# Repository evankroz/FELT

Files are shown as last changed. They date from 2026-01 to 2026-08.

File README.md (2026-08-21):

# FELT - Flight Environment Logging and Telemetry
A *light*weight (light as felt) Arduino system for logging, primarily altitude, data using the Adafruit Feather M0 Adalogger and DPS310 pressure sensor.
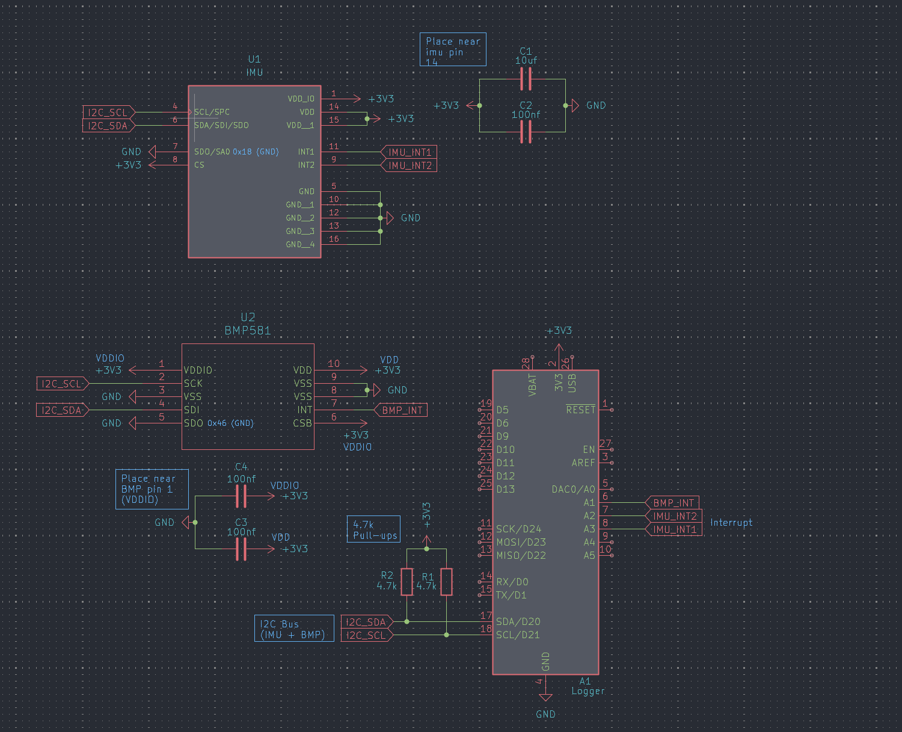
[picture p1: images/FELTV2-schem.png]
FELT V2 Schematic (In Progress)

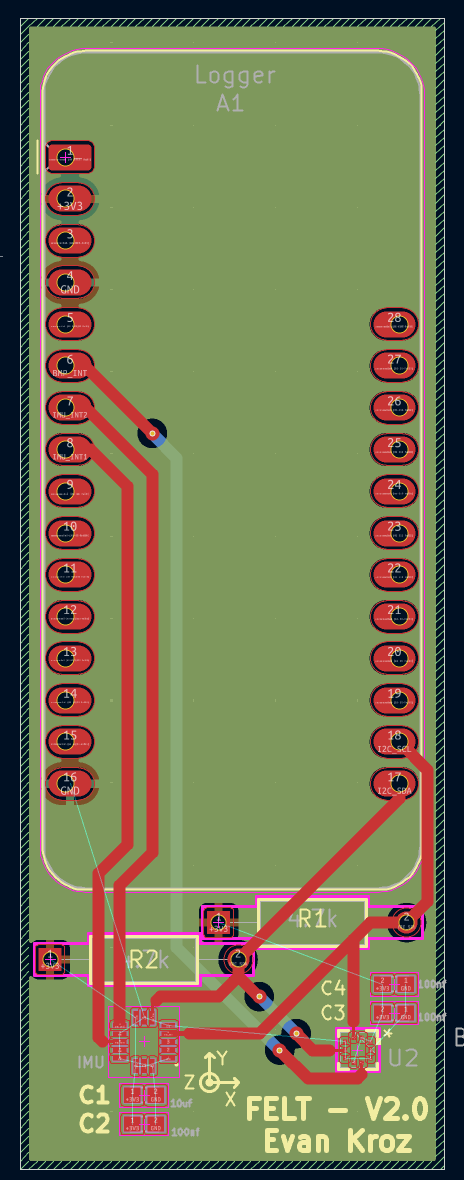
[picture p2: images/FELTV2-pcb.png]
FELT V2 PCB (In Progress)


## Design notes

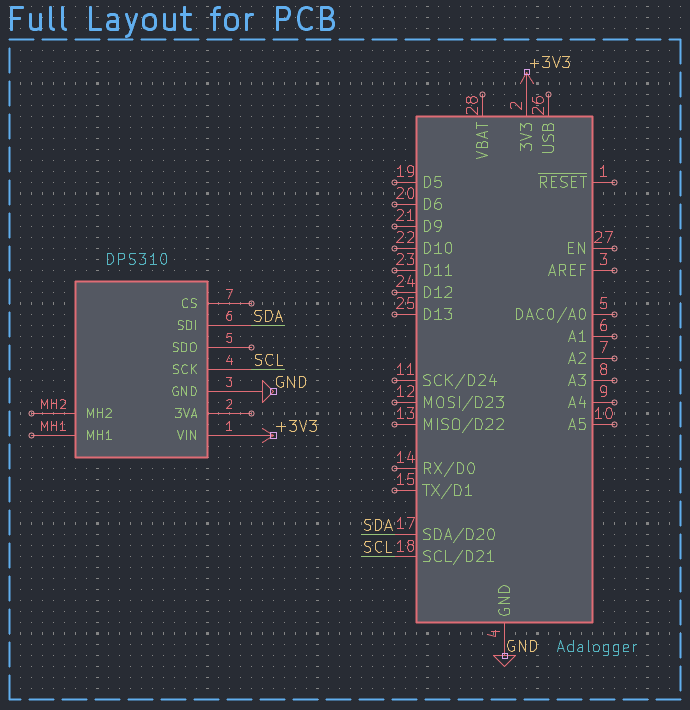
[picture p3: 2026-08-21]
images/FELTV1-schem.png

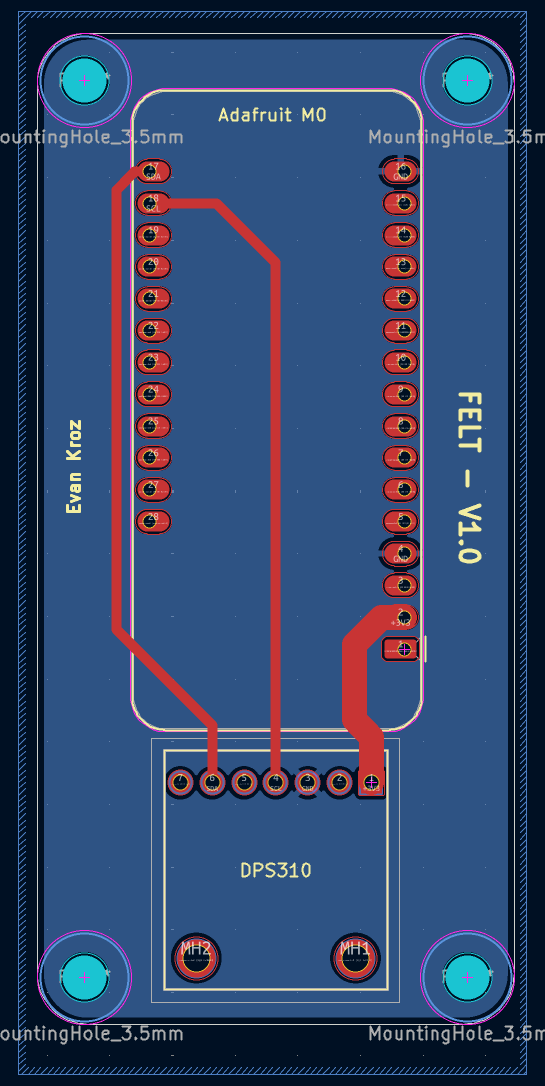
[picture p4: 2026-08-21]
images/FELTV1-pcb.png

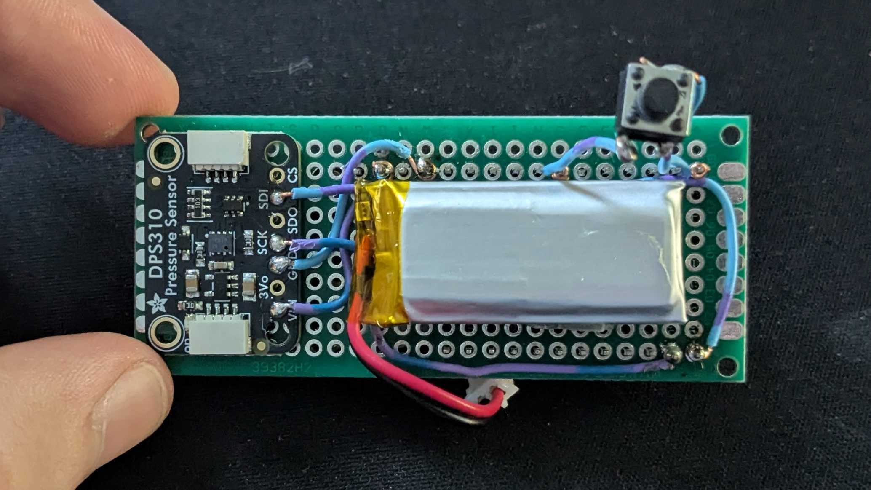
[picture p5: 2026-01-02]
images/FELTV0.jpg

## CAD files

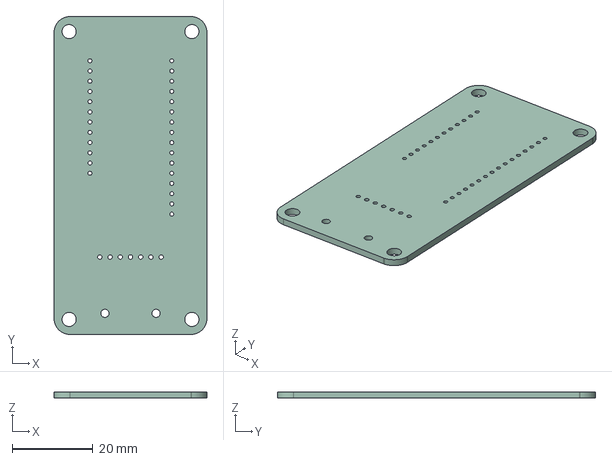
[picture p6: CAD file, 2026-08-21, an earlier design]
FELT_V1/FELT_V1.step
38.0 x 79.0 x 1.60 mm

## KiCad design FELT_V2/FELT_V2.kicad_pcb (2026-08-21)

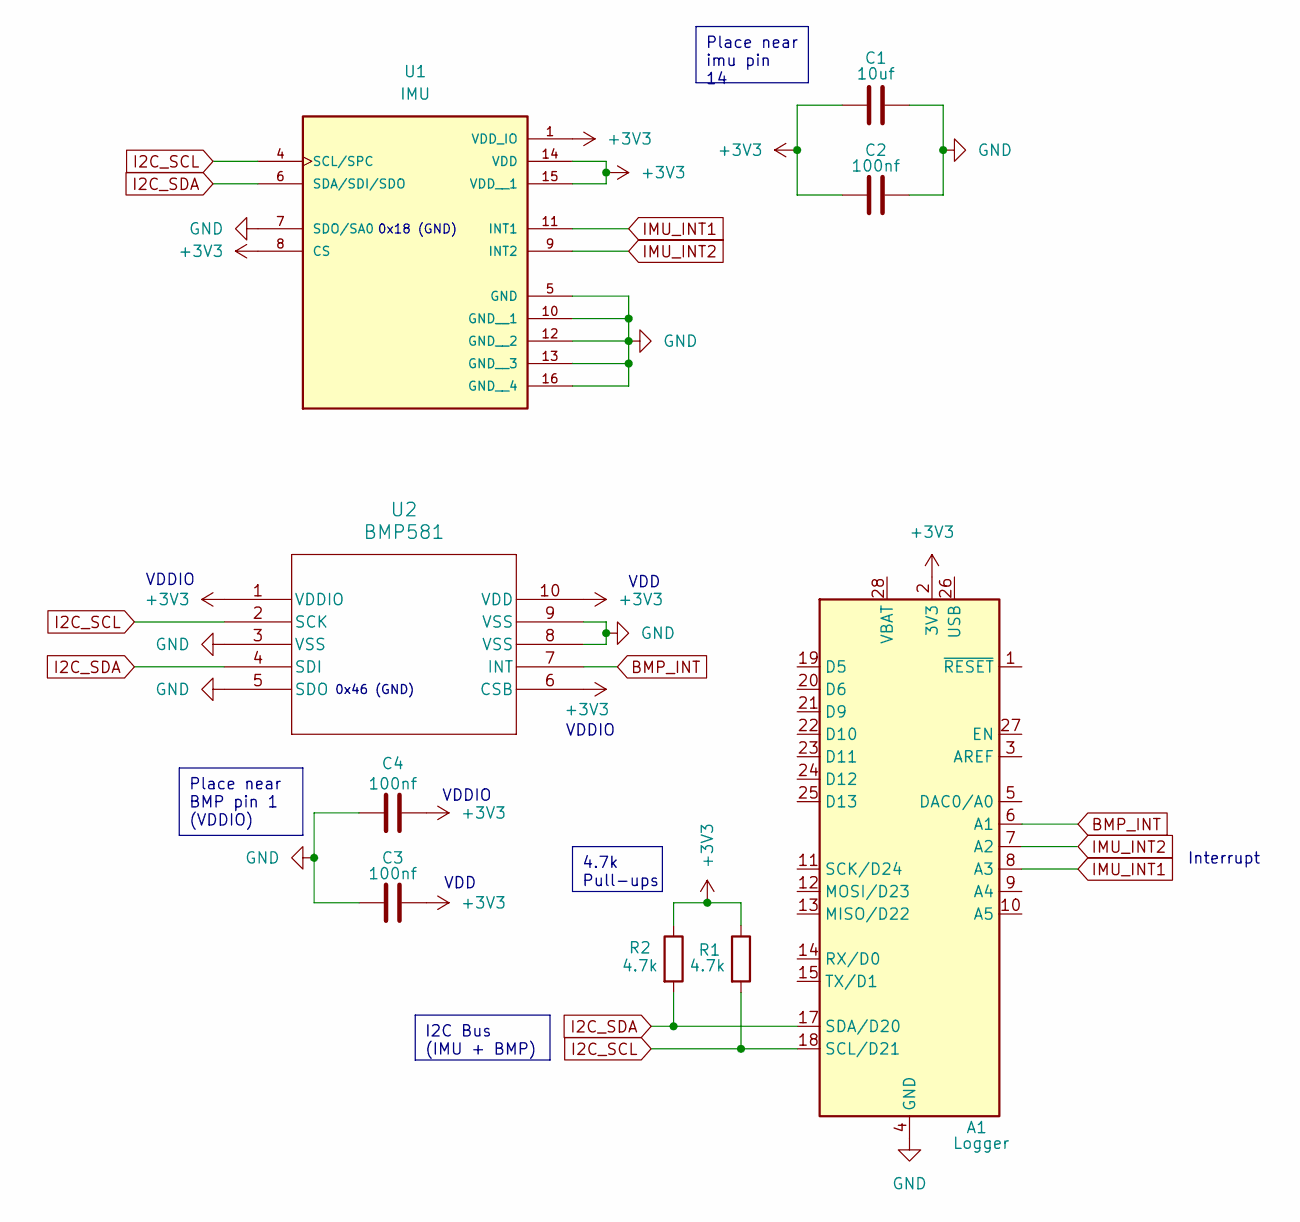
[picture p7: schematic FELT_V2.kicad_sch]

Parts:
A1: Logger; Adafruit_Feather
C1: 10uf; CAPC1608X90N
C2, C3, C4: 100nf; CAPC1608X90N
R1, R2: 4.7k; STA_CF14_STP
U1: IMU; QFN300X300X100-16N
U2: BMP581; QFN10_BMP581_BOS

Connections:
+3V3: A1.2 (3V3), C1.1, C2.1, C3.2, C4.2, R1.1, R2.1, U1.1 (VDD_IO), U1.8 (CS), U1.14 (VDD), U1.15 (VDD__1), U2.1 (VDDIO), U2.6 (CSB), U2.10 (VDD)
BMP_INT: A1.6 (A1), U2.7 (INT)
GND: A1.4 (GND), A1.16 (GND), C1.2, C2.2, C3.1, C4.1, U1.5 (GND), U1.7 (SDO/SA0), U1.10 (GND__1), U1.12 (GND__2), U1.13 (GND__3), U1.16 (GND__4), U2.3 (VSS), U2.5 (SDO), U2.8 (VSS), U2.9 (VSS)
I2C_SCL: A1.18 (SCL/D21), R1.2, U1.4 (SCL/SPC), U2.2 (SCK)
I2C_SDA: A1.17 (SDA/D20), R2.2, U1.6 (SDA/SDI/SDO), U2.4 (SDI)
IMU_INT1: A1.8 (A3), U1.11 (INT1)
IMU_INT2: A1.7 (A2), U1.9 (INT2)

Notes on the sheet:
I2C Bus (IMU + BMP)
4.7k Pull-ups
Place near imu pin 14
Place near BMP pin 1 (VDDIO)
VDD
VDDIO
0x46 (GND)
0x18 (GND)
Interrupt

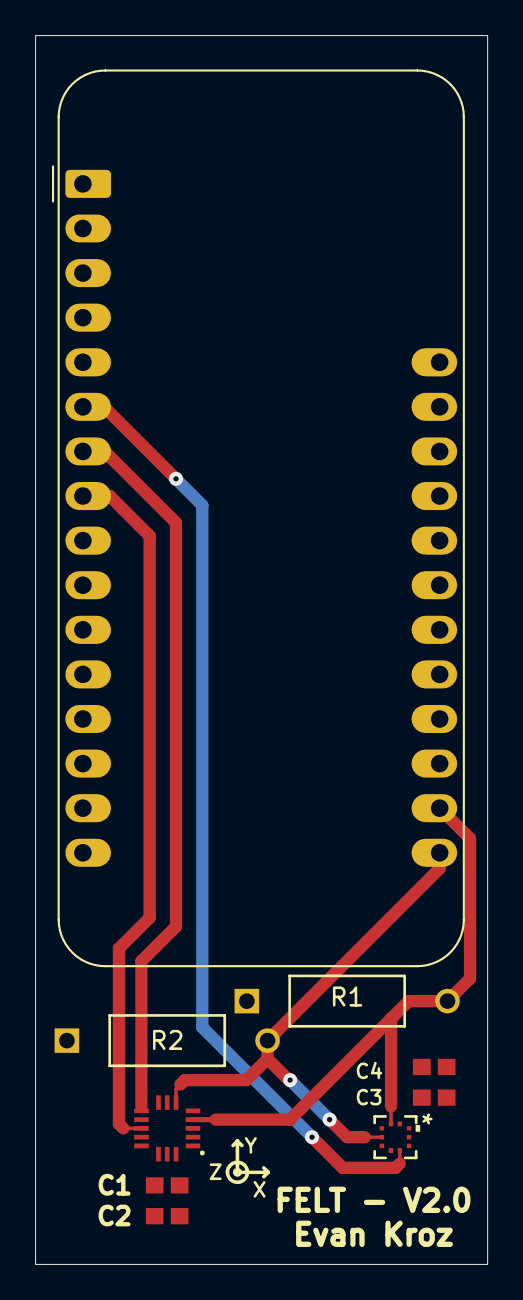
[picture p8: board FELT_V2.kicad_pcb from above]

Board: 4 copper layers, 25.8 x 70.0 mm, 9 parts (0 on the bottom side), 7 nets.

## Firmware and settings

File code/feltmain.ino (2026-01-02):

#include <Wire.h>
#include <Adafruit_DPS310.h>
#include <SD.h>

#define BUTTON_PIN A5
#define LED_PIN    8

Adafruit_DPS310 dps;
File logfile;

bool readyToStart = false;   // Button armed state
bool readyDelay = false;     // 5-second ready indicator active
bool launched = false;

unsigned long readyStartMillis = 0;
unsigned long loggingStartMillis = 0;
unsigned long lastSampleMillis = 0;

// For a 10s buffer at 60Hz: 10*60 = 600
const uint16_t BUFFER_SIZE = 600;

struct DataPoint {
  unsigned long timestamp;  // millis() relative to logging start
  float altitude;           // meters
};

// Circular buffer for pre-launch data
DataPoint buffer[BUFFER_SIZE];
uint16_t bufIndex = 0;
bool bufFull = false;

float launchAltitude = 0;

void setup() {
  Serial.begin(115200);
  pinMode(BUTTON_PIN, INPUT_PULLUP);
  pinMode(LED_PIN, OUTPUT);
  digitalWrite(LED_PIN, LOW);

  while (!SD.begin(4)) {
    Serial.println("SD initialization failed!");
    delay(1000);
  }

  if (!dps.begin_I2C()) {
    Serial.println("Couldn't find DPS310!");
    while (1);
  }

  Serial.println("Ready. Press button to arm; LED will show 5s green before buffering data.");
}

void openNewLogFile() {
  char filename[12];
  for (int i = 0; i < 100; i++) {
    sprintf(filename, "%02d.csv", i);
    if (!SD.exists(filename)) {
      logfile = SD.open(filename, FILE_WRITE);
      if (logfile) {
        logfile.println("Timestamp,Altitude_m");
        logfile.flush();
        Serial.print("Logging to file: ");
        Serial.println(filename);
        return;
      }
    }
  }
  Serial.println("Error: couldn't create log file!");
}

void writeBufferToFile() {
  Serial.println("Writing buffered data to file...");
  for (uint16_t i = 0; i < (bufFull ? BUFFER_SIZE : bufIndex); i++) {
    DataPoint &dp = buffer[i];
    unsigned long ms = dp.timestamp;
    unsigned int minutes = (ms / 60000) % 60;
    unsigned int seconds = (ms / 1000) % 60;
    unsigned int msecs = ms % 1000;
    char timeStr[16];
    sprintf(timeStr, "%02u:%02u:%03u", minutes, seconds, msecs);

    logfile.print(timeStr);
    logfile.print(",");
    logfile.println(dp.altitude, 2);
  }
  logfile.flush();
  Serial.println("Buffer write complete.");
}

void loop() {
  static unsigned long lastButtonPress = 0;

  unsigned long currentMillis = millis();

  // Button press: start the 5-second ready period if not already armed or launched
  if (!readyToStart && !readyDelay && digitalRead(BUTTON_PIN) == LOW) {
    if (currentMillis - lastButtonPress > 300) {  // debounce 300ms
      readyDelay = true;
      readyStartMillis = currentMillis;
      Serial.println("Button pressed: Starting 5-second ready indicator...");
      digitalWrite(LED_PIN, HIGH); // Turn LED on steady green during ready delay
    }
    lastButtonPress = currentMillis;
  }

  // Handle the 5-second ready delay period
  if (readyDelay) {
    if (currentMillis - readyStartMillis >= 5000) {  // 5 seconds elapsed
      readyDelay = false;
      readyToStart = true;
      launchAltitude = 0;
      bufIndex = 0;
      bufFull = false;
      Serial.println("Ready period ended. Starting buffering for launch...");
      // LED remains on steady green during buffering
      digitalWrite(LED_PIN, HIGH);
    }
  }

  // If armed, not launched yet: buffer data and check for launch
  if (readyToStart && !launched && (currentMillis - lastSampleMillis >= 17)) { // 17 ms = ~60Hz
    lastSampleMillis = currentMillis;

    sensors_event_t temp_event, pressure_event;
    dps.getEvents(&temp_event, &pressure_event);
    float altitude = 44330 * (1.0 - pow(pressure_event.pressure / 1013.25, 0.1903));

    if (launchAltitude == 0) {
      launchAltitude = altitude;
      Serial.print("Baseline altitude: ");
      Serial.println(launchAltitude, 2);
    }

    // Store in circular buffer
    buffer[bufIndex].timestamp = currentMillis;
    buffer[bufIndex].altitude = altitude;
    bufIndex = (bufIndex + 1) % BUFFER_SIZE;
    if (bufIndex == 0) bufFull = true;

    // Serial.print("Buffered altitude: ");
    // Serial.println(altitude, 2);

    // Detect launch: altitude rise >= 2m
    if (altitude - launchAltitude >= 30) {
      Serial.println("Launch detected! Starting logging...");
      launched = true;
      openNewLogFile();
      writeBufferToFile();
      loggingStartMillis = currentMillis;
      // Keep LED on steady during logging
      digitalWrite(LED_PIN, HIGH);
    }
  }

  // Once launched, log live data every 17 ms (~60 Hz)
  if (launched && (currentMillis - lastSampleMillis >= 17)) {
    lastSampleMillis = currentMillis;

    sensors_event_t temp_event, pressure_event;
    dps.getEvents(&temp_event, &pressure_event);

    float altitude = 44330 * (1.0 - pow(pressure_event.pressure / 1013.25, 0.1903));

    unsigned long elapsedMs = currentMillis - loggingStartMillis;
    unsigned int minutes = (elapsedMs / 60000) % 60;
    unsigned int seconds = (elapsedMs / 1000) % 60;
    unsigned int msecs = elapsedMs % 1000;

    char timeStr[16];
    sprintf(timeStr, "%02u:%02u:%03u", minutes, seconds, msecs);

    Serial.print(timeStr);
    Serial.print(", ");
    Serial.println(altitude, 2);

    logfile.print(timeStr);
    logfile.print(",");
    logfile.println(altitude, 2);
    logfile.flush();
  }
}

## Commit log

2026-08-21 Rename Screenshot 2026-08-21 160706.png to FELTV1-pcb.png
2026-08-21 Rename Screenshot 2026-08-21 160829.png to FELTV1-pcb.png
2026-08-21 Add FELT_V1.kicad_pcb file
    [FELT_V1.kicad_pcb]
2026-08-21 Add FELT_V1.kicad_prl file
2026-08-21 Add FELT_V1-B_Cu.gbr file
    [FELT_V1-B_Cu.gbr]
